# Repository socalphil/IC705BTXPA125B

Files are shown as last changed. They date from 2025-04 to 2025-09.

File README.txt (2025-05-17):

To update firmware please use the following procedure:

Go to the webpage https://github.com/marcelstoer/nodemcu-pyflasher/releases
Download the release for your operating system.
Connect the unit with the supplied USBA to C cable.
Run the downloaded EXE. NodeMCU
1)Set your COM Port 
2)Choose the firmware in firmware in the main folder.(Recently mailed units will use firmware named R2 older units that were shipped before the new colored ones are R1)
3)Set baud rate as 115200 
4)Flash mode Dual I/O(DIO)
5) Erase flash (no)
6) Click FlashModeMCU
7) After flash the screen will remain black. Remove USB and reinsert.
8) Unit should boot correctly.

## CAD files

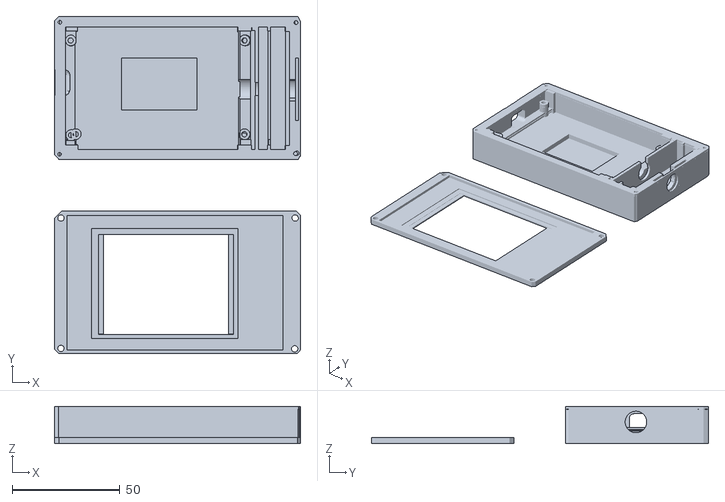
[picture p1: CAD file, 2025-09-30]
3D/IC705BT Case and top_final_new_case.stl
114.2 x 156.4 x 17.4

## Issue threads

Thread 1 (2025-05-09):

XPA125B Firmware v2.0.1 Voltage Mismatch issue

d3vnu11, 2025-05-09:
Mentioned version of the firmware uses difference voltages for band switching causing the controller to send wrong voltage resulting in the wrong band being selected on the XPA125b.

Reached out to Radiooddity and was kind enough to forward the new voltages using in the Version 2.0.1 firmware. Adding for completeness that way I'm not the only person with this info :) I haven't had a chance to update the code maybe this weekend.

Band / Voltage

1.8MHz / 230mV
3.5MHz / 460mV
5.0MHz / 690mV
7MHz    / 920mV
10MHz  / 1150mV
14MHz  / 1380mV
18MHz / 1610MV
21Mhz / 1840Mv
24MHz / 2070mV
28MHz / 2300mV
50MHz / 2530mV

Love the new case design and screen layout !

socalphil, 2025-05-10:
Hi Kevin

Thank you for that it really helps. I can modify my version for the new
voltages. But it may break the folks on the older versions. I may try to
add a startup toggle to the splash screen to ask which version is used and
change the voltage accordingly.
It shouldn't be too bad. Just need to figure out the selection check box.

I will modify this weekend hopefully and post to github.

73

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

d3vnu11, 2025-05-10:
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

I haven't had success in getting it to compile in Arduino IDE.  But what was given to me from Radiooddity  was basically what was already in your code. but starting at 20M the voltage is too low seems like 25-35mv more needs to be added to each band from 20M to 6M.. I saw in the original implementation

  `int corrFact; // because if a load exist like PA we will have a lower, non-linear voltage output as calculated
  corrFact = 0; // add a little bit more mV, here` with R=470Ohm and C=22uF at PIN 27`

....
 // 20M
  corrFact = 35;
  bandvoltage = bandvoltage + corrFact; `

where they have a correction variable and each band can then be tweaked until it works correctly. Which seems like what will be needed to fix it for people on the latest firmware. Anyway I'm done poking around for today will rollback the amp back to the older version for the time being.

73
KC3VPY.

socalphil, 2025-05-10:
Yup. I am trying to see if I can provide a binary file and use esp32
flasher.

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

socalphil, 2025-05-10:
I have added a firmware folder. Run the pyflasher program. Select your com port and load the BIN file in the NodeMCU firmware. BAUD rate 115200. Flash mode Dual I/O. Dont erase flash. Flash NodeMCU. If it works okay as I am sure it will I can then add to the voltages and if you could test with 2.01.

d3vnu11, 2025-05-10:
Worked I used the MacOS dmg release of the flasher as I was running into winblows 11 driver issues.. I am now running https://github.com/socalphil/IC705BTXPA125B/blob/main/Firmware/CIV_template_master_rev2_final.ino.merged.bin version of the binary. looks great !

d3vnu11, 2025-05-10:
FYI with either bin files band switching isn't working at XPA125B selects 6m band and stays there no matter what band is selected on the radio. I am on the old version of the device is that makes a difference the version with the black printed case..

socalphil, 2025-05-11:
Can you try the new file.

On Sat, May 10, 2025 at 2:43 PM Kevin Jones ***@***.***>
wrote:

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

d3vnu11, 2025-05-11:
That latest version for the old HW working it is now switching bands again.

socalphil, 2025-05-16:
Will send new FW today with updated voltages.

On Sun, May 11, 2025 at 7:10 AM Kevin Jones ***@***.***>
wrote:

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

socalphil, 2025-05-16:
This is for Rev 2.01

On Fri, May 16, 2025 at 2:51 PM phillip sher ***@***.***>
wrote:

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
>>> *d3vnu11* left a comment (socalphil/IC705BTXPA125B#1)
>>> <https://github.com/socalphil/IC705BTXPA125B/issues/1#issuecomment-2869885829>
>>>
>>> so I re-udiated to v20.1 of the XPA firmware and running the Last bin
>>> you sent seems like now 160m through 20M align correctly all though 20m
>>> seems to lag in switching the amp to 20M (maybe voltage fluctuations in the
>>> PA might be right on the edge of it's limit there). So if you get a chance
>>> you can tweak voltages for 20M through 50M I'll test them for ya. then once
>>> we get them tweaked should be adaptable to either version of your
>>> controller ! Great project btw works rather well on the old XPA firmware..
>>>
>>> —
>>> Reply to this email directly, view it on GitHub
>>> <https://github.com/socalphil/IC705BTXPA125B/issues/1#issuecomment-2869885829>,
>>> or unsubscribe
>>> <https://github.com/notifications/unsubscribe-auth/AOVJCNE56KUIXI7PNFJPYML255K4DAVCNFSM6AAAAAB4Z7TGESVHI2DSMVQWIX3LMV43OSLTON2WKQ3PNVWWK3TUHMZDQNRZHA4DKOBSHE>
>>> .
>>> You are receiving this because you commented.Message ID:
>>> ***@***.***>
>>>
>>

d3vnu11, 2025-05-17:
Hey last version you sent band switching does't work at all again. Think it might be for your revised hardware and not the old version of hardware..

Regards.
73

socalphil, 2025-05-17:
Hi Kevin

Please use the R1 version in the firmware directory.

On Fri, May 16, 2025 at 6:11 PM Kevin Jones ***@***.***>
wrote:

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

d3vnu11, 2025-05-17:
Ok great downloaded R1 version 80-17M are rock solid (tested with FT8). between 17M and 15M-6M needs adjusting 15M is almost there so add a little voltage to 15M then bigger additions of voltage to the rest of them up to 6M for reference when I have 6M selected on the radio the amp selects the 10M filter group hope this helps on how much more voltage will be needed.

--Kev

73

d3vnu11, 2025-05-17:
Actually let me revise after further testing 80-12M are solid only 10M and 6M need more voltage. with 10M band selected on radio AMP remains on 12M when 6M is select amp switches to 10M.

--Kev
73

socalphil, 2025-05-17:
Hi Kevin

Can you try the new R1 I posted to Github. I apologize, I should be doing
this testing, but I am redoing my antenna system and shack layout so it is
all disconnected for now. Should be back next week some time, hopefully.
Just waiting for some RF relays to switch the antennas.

73

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

d3vnu11, 2025-05-17:
Works great ! Was a pleasure to help test.. Hopefully you'll get your shack back running ASAP and I'll see ya down the log. Thanks again !
--Kev

73

socalphil, 2025-05-17:
Hi Kevin. Thanks so much for testing. I live in a HOA so have to hide
antennas so running cable in the attic and adding antenna switching to
switch my two verticals is a bit tricky but most of the way there. 73

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

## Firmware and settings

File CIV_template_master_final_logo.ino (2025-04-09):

#include <TFT_eSPI.h>


// Edit by PA5MR && PE1OFO
// z_userprog from VK3PE17

/* 
CIV_template - an easy to use example for handling a communication channel to ICOM radios

  Created by Wilfried Dilling, DK8RW, May 2022
  Released into the public domain


This Arduino sketch is based on and uses the library "CIVmasterLib" written and released to 
the public domain by Wilfried Dillig, DK8RW in May 2022 or newer.


It is fully functional, but carries in addition lots of comments in order to make it better
understandable.
The SW has also been structured in several tabs in order to make it easier for the user to
create own sketches based on CIVmasterLib.
Put your own code in the (almost) empty tab "z_userprog.ino" and put the calls to 
your procedures into one of the places marked with "//!//"

Don't worry - although this sketch looks big (because of lots of explaining comments), you 
don't have to work through and understand the whole code in order to create a running system
- just look for "//!//" to put your calls to your own code in file "z_userprog.ino"


Tasks: 
- this is a template, which shall show how the CIV class, i.e. a single point to point 
  connection between a CI-V master(Arduino or ESP32) and an ICOM radio is utilized best based
  on CIVmasterLib

- by default it processes the following infos:
  - is the radio ON or OFF ?
  - is the radio in TX or RX mode ?
  - which frequency is in use by the radio ?
  
- optional also the following info is processed:
  - which modulation mode and which RX-Filter is in use ? (enable with "modmode" in a_defines.h)

For a first impression, compile the unmodified sketch and let it run on an ESP32 or on one of the
supprted Arduino boards and have a look into the Serial Monitor (Baudrate 115200).

Of course, this Sketch can also be used to control the radios - just add your commands to the radio
in "CiV_sendCmds()", but this has not been covered by this example yet (another example to come?).


!!! New !!! 28.05.22   fastPTT !

Thanks to the info from PU5VEN via VK3PE about one specific ICOM command, I have been able to implement
a "fastPTT" mode !
By this, the PTT delay from 80ms(average)..130ms could be reduced down to 10ms(average)..30ms! 
This is much faster and in the range which the IC705 can compensate :-)

So, the risk of blowing something up has decreased significantly, hi.
However, this is all SW, so the note below still applies ;-)

Note: Please be careful if you want to use the RX/TX info as a PTT for PAs - the delay is
      pretty high, unfortunately - something between 12ms and 130ms!  (fastPTT: 30ms max !)
      The IC705 can only compensate 30ms.
      It is your own responsibility to ensure, that no damage occures to your radio or the PA 
      in the case, when the PTT change RX->TX comes later than the HF-power from the radio.


*/

// includes ---------------------------------------------------------------------


#include <CIVmaster.h>  // CIVcmds.h will be included automatically in addition

//!!!!!!!!!!!!!!!!!!!!!!!!!!!!!!!!!!!!!!!!!!!!!!!!!!!!!!!!!!!!!!!!!!!!!!!!!!!!!!!
// First, select the radio in use by commenting/uncommenting the matching lines ! 
//!//

//---------------------------------------
//IC705 (via Bluetooth, default):
  #define useBT
  #define fastPTT
  uint8_t civAddr = CIV_ADDR_705;
//---------------------------------------
//IC7300:
//IC7300 doesn't support fastPTT !
//  uint8_t civAddr = CIV_ADDR_7300;
//---------------------------------------
//IC9700:
//  #define fastPTT
//  uint8_t civAddr = CIV_ADDR_9700;


//!!!!!!!!!!!!!!!!!!!!!!!!!!!!!!!!!!!!!!!!!!!!!!!!!!!!!!!!!!!!!!!!!!!!!!!!!!!!!!!
// Please don't forget to set debug mode ON or OFF according your wishes in the
// include file "a_defines.h" (default is debug mode ON) !
//!!!!!!!!!!!!!!!!!!!!!!!!!!!!!!!!!!!!!!!!!!!!!!!!!!!!!!!!!!!!!!!!!!!!!!!!!!!!!!!
#include "a_defines.h"


//-------------------------------------------------------------------------------
// create the civ object in use

CIV     civ;    // create the CIV-Interface object; by this you can easily access
                // the interface to the radio later on

// module wide variables --------------------------------------------------------

// this is the structure, which carries the result of the civ-methods writeMsg and readMsg
CIVresult_t CIVresultL;

/*
parameters of the structure CIVresult_t:
.retVal         // the summary/result of the command processing like CIV_OK, CIV_NOK,  ...
.address        // the address of the radio which got/sent the message
.cmd[5]         // the command, which has been sent/got by the radio; cmd[0]= length of the command
.datafield[10]  // the data, which has been sent/got by the radio; datafield[0]= length of the data
.value          // if the datafield carries valid data, here is the binary number. Otherwise set to 0
and

possible return values (retVal_t):
  CIV_OK           =  0,  // valid command received by the radio and accepted
  CIV_OK_DAV       =  1,  // valid command received by the radio, accepted and data (e.g. frequency)
                          // are available

  
  // this is the border between good and bad and will be used as such -----------------

  CIV_NOK          =  2,  // command received by the radio, but NOT accepted; something is wrong
  CIV_HW_FAULT     =  3,  // onewire bus: dataline is shortcut to ground
  CIV_BUS_BUSY     =  4,  // onewire bus: attempt to send data failed, because of traffic on the bus 
  CIV_BUS_CONFLICT =  5,  // onewire bus: attempt to send data failed because of bus collision
  CIV_NO_MSG       =  6   // no answer from the radio !

 ... see also CIVmaster.h ...
*/

// some control variables/timers:

// with these timestamps time differences of up to 65535 ms == 1min 5,5sec max. can be handled

// uint16_t is used here in order to save RAM space (because of the small Atmel processors)

uint16_t    ts_CIVcmdSent = 0;   // time stamp[ms] of the last command sent 
                                 // this is common for all commands, the last wins !
                                 // used for determining the timeout
uint16_t    ts_RXTX_sent  = 0;   // time stamp[ms] of the last RXTX query sent to the radio
uint16_t    ts_f_sent     = 0;   // time stamp[ms] of the last frequency query sent to the radio

int bandvoltage;     // For Xiegu XPA125B
#define LED 27       //Band voltage
#define C_RELAIS  25 //Coax relais HF / VHF-UHF

// For analogue PWM 
int brightness = 0;
const int freq = 5000; //PWM Freq
const int ledChannel = 0;
const int resolution = 10; //Resolution 8, 10, 12, 15



#ifdef modmode
uint16_t    ts_Mod_sent   = 0;   // time stamp[ms] of the last ModMode query sent to the radio
#endif
//!// put here additional timers in case you are adding additional queries


bool        CIVwaitForAnswer = false; // if true, a command has been sent to the radio which
                                      // has not been answered yet


// Global variables of the radio data -------------------------------------------
// in general, the initial values are set to an undefined state in order 
// to force necessary actions initially after connecting to the radio

// "database" variables:

radioOnOff_t    G_radioOn   = RADIO_NDEF; // don't know initially, whether the radio 
                                          // is switched on and connected
bool            G_RXTX      = 0;          // 0 == RX; 1 == TX on
unsigned long   G_frequency = 0;          // operating frequency in [Hz]
uint8_t         G_Mod       = MOD_NDEF;   // Modulation mode (USB, LSB, etc...)
uint8_t         G_RXfilter  = FIL_NDEF;   // RXfilter in use (Fil1, Fil2, Fil3);

//!//    put additional variables here, if necessary ... or put them into file z_userprog.ino


// timer  variables -------------------------------------------------------------
uint16_t t_curr_lp;       // temporary time of the current baseloop (at the beginning) for calculations
uint16_t ts_last_lp;      // time stamp - will be updated at the end of every baseloop run

//=============================================================================================

//==========  General initialization  of  the system  =========================================

void setup() {

  // initialize the serial interface (for debug messages)
  Serial.begin(debugBdRate);
  Serial.println("");
  delay(100);
  Serial.println (VERSION_STRING);
  

  // initialize the civ object/module (true means "use BT" in case of the ESP32)
  #ifdef useBT
    civ.setupp(true); // BT
  #else
    civ.setupp();     // onewire (HW)
  #endif

  // tell civ, which address of the radio is to be used
  civ.registerAddr(civAddr);

// note: in fastPTT mode this may be significantly slower, since it doesn't influence the PTT delay in this case
  init_delayMeas; // debugging on ESP32: setup the PTT delay measurement

  //!// put your setup code (independent from civ) here ... or put it into file z_userprog.ino
  userSetup();

  // initialise the baseloop timers ...
  t_curr_lp = millis();
  ts_last_lp = t_curr_lp;

  // PA5MR
    
  //ledcSetup(ledChannel, freq, resolution);
  //ledcAttachPin(LED, ledChannel);
  ledcAttach(LED, freq, resolution);  // Modified code to work with new ESP32 Arduino IDE

  
}

//============================  main  loop ====================================================

void loop() {

  t_curr_lp = millis();
  
  if (uint16_t(t_curr_lp - ts_last_lp) >= BASELOOP_TICK) {
    // payload ------------------------------------------------------
  
    set_delayMeas;  // debugging on ESP32: check the trigger input and store the time when input changes

    // first, read and process the answers from the radio (if available)
    CIV_getProcessAnswers();

    // second, write commands to the radio (if possible and necessary)
    CIV_sendCmds();

    // at this point, all avaliable data of the radio have been handled - CIV processing done !
    // the variables in the "database" variables have been updated, if necessary you can work with them

    //!// put your base loop code (independent from civ) here ... or put it into file z_userprog.ino
    userBaseLoop();
  
    // payload ------------------------------------------------------
    ts_last_lp = t_curr_lp;
	} // if BASELOOP_TICK
  
} // end loop

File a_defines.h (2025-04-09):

#ifndef defines_h
#define defines_h

/* 
CIV_template - a_Defines.h / general definitions
*/

#define VERSION_STRING "CIV_template V0_4 May 31st, 2022"

// if defined, debug messages on the serial line will be generated
// default: active, i.e.uncommented
#define debug 

// if defined, also the Modulation Mode parameters of the radio are processed
// default: inactive, i.e. commented out (since this is not needed in most of the cases)
#define modmode

// if defined, a triggerinput on (Pin 16 of ESP32) is used for exact time measurements
// this is useful for checking the time delay of the PTT signal generated by ESP32
// !!! only possible, when using BT on ESP32, otherwise these pins are used as COM2 for CIV
//#define ESPtriggerMeas

// Global compile switches ===================================================================================


// some general defines --------------------------------------------------------------------------------------

// HW pins in use:

// Arduino uno, nano, Pro mini etc.
// Pin 08 and 09    Altsoftserial COM for CIV HW onewire

// Arduino 2560
// Pin 18 and 19    COM1 for CIV HW onewire

// ESP32:
// Pin 16 and 17    COM2 for CIV HW onewire 
// Pin 16           Trigger for timing measurements (debugging) in case of CIV via Bluetooth

//------------------------------------------------------------------------------------------------------------
// times and timers ...

// repetition rate of the base loop in ms, i.e. every 10ms an action can/will be taken
#define BASELOOP_TICK 10
// note: you can reduce the PTT delay down to 15ms max in fastPTT mode, if you set BASELOOP_TICK to 5ms
//#define BASELOOP_TICK 5

// this is the maximum time in ms which the radio may take for answering a query
#define t_waitForAnswer 900

// this is the polling time in ms for the RXTX query
// in case of fastPTT in may be significantly longer, since it has no influence on the PTT delay !
#ifdef fastPTT
  #define t_RXTXquery 370
#else
  #define t_RXTXquery 80
#endif

// this is the polling time in ms for the slow poll queries of frequency, ModMode
#define t_slowQuery 1000

// this is the waiting time after sending a command before processing an answer 
// only necessary in case of fast polling the RXTX state
#ifndef fastPTT
  #define t_gapAfterquery 20
#endif

//------------------------------------------------------------------------------------------------------------

enum onOff_t:uint8_t {
	OFF = 0,
	ON  = 1,
  NDEF
};

enum radioOnOff_t:uint8_t {
  RADIO_OFF = 0,
  RADIO_ON  = 1,
  RADIO_OFF_TR,     // transit from OFF to ON
  RADIO_ON_TR,      // transit from ON to OFF
  RADIO_NDEF,       // don't know
  RADIO_TOGGLE
};

// Strings are needed only if you want to output something in Serial Monitor,
// otherwise: save RAM !!
#ifdef debug
const String  radioOnOffStr[6] = {
  "R_OFF",
  "R_ON",
  "R_OFF_TR",     // transit from OFF to ON
  "R_ON_TR",      // transit from ON to OFF
  "R_NDEF",       // don't know
  "R_TOGGLE"
};

const String    RXTXstr[2] = {
"RX", // 0 or false
"TX"  // 1 or true
};
#endif


// modulation mode according to ICOMs documentation
enum radioModMode_t:uint8_t {
  MOD_LSB     = 0,
  MOD_USB,
  MOD_AM,
  MOD_CW,
  MOD_RTTY,
  MOD_FM,
  MOD_WFM,
  MOD_CW_R,
  MOD_RTTY_R,
  MOD_DV,   // 09 (Note: on the ICOM CIV bus, this is coded as 17 in BCD-code, i.e. 0x17)
  MOD_NDEF
};

// clear test translation of the modulation modes
#if defined(debug) && defined(modmode)
const String modModeStr[11] = {
  "LSB   ", // 00 (00 .. 08 is according to ICOM's documentation) 
  "USB   ", // 01
  "AM    ", // 02
  "CW    ", // 03
  "RTTY  ", // 04
  "FM    ", // 05
  "WFM   ", // 06
  "CW-R  ", // 07
  "RTTY-R", // 08
  "DV    ", // 09 (Note: on the ICOM CIV bus, this is coded as 17 in BCD-code, i.e. 0x17)
  "NDEF  "  // 10
};
#endif

// RX filter chosen according to ICOMs documentation
enum radioFilter_t:uint8_t {
  FIL_NDEF    = 0,
  FIL1        = 1,
  FIL2,
  FIL3
};

// clear text translation of the Filter setting
#if defined(debug) && defined(modmode)
const String FilStr[4] = {
  "NDEF",
  "FIL1",   // 1 (1 .. 3 is according to ICOM's documentation)
  "FIL2",
  "FIL3"
};
#endif

//!// put your own defines here if necessary:
// e.g. :


//------------------------------------------------------------------------------------------------------------
// Debugging ...

// Speed of the Serial output messages
#define debugBdRate 115200
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

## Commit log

2025-09-30 Create CASE AND MAIN
2025-09-30 3D directory
    [IC705BT Case and top_final_new_case.stl]
